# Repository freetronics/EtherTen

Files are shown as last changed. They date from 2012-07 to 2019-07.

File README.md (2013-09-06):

Freetronics EtherTen
====================
Copyright 2010-2013 Freetronics Pty Ltd  
Freetronics site:  www.freetronics.com  
Freetronics email: info@freetronics.com  

The EtherTen is a 100% Arduino Compatible Board, based on the Arduino
Uno reference design, but with improvements and updates for ease of use, cost
and getting started. It also includes on-board Ethernet with PoE (Power
-over-Ethernet) support.

Features:

 * LEDs visible on the edge
 * Micro-USB Connector
 * I2C MAC address ROM
 * Overlay guide where you need it (both top and bottom)
 * D13 pin works for everything
 * RX pin biased
 * Mounting holes, power and X3 pads
 * All connections in the same place

You can view more at our product page at:

  http://www.freetronics.com/etherten

This repository includes a handy copy of the schematic in PDF format.

INSTALLATION
------------
The design is saved as an EAGLE project. EAGLE PCB design software is
available from www.cadsoftusa.com free for non-commercial use. To use
this project download it and place the directory containing these files
into the "eagle" directory on your computer. Then open EAGLE and
navigate to Projects -> eagle -> EtherTen.

DISTRIBUTION
------------
The specific terms of distribution of this project are governed by the
license referenced below.

LICENSE
-------
This work is licensed under the
Creative Commons Attribution-Share Alike License.  
To view a copy of this license, visit

  http://creativecommons.org/licenses/by-sa/3.0/  
  http://creativecommons.org/licenses/by-sa/3.0/legalcode

or send a letter to

  Creative Commons  
  171 Second Street, Suite 300  
  San Francisco  
  California, 94105  
  USA

The "license" folder within this repository also contains copies of the
licences referenced above.

CREDITS
-------
The EtherTen was designed by Marc Alexander (marc@freetronics.com) and
Jonathan Oxer (jon@freetronics.com) based on previous work by the Arduino
team (www.arduino.cc/playground/Main/People) which includes:

 * Massimo Banzi
 * David Cuartielles
 * Tom Igoe
 * Gianluca Martino
 * David A. Mellis

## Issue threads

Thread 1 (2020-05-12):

uSD_nCS inhibits use of D4 as INPUT_PULLUP

berossm, 2020-05-12:
The uSD_nCS line passes to ground through RN6 & RN8.  As a result this overcomes the internal pull-up for D4.

For my application I needed all of inputs as pull-up.  To work around this I removed RN8 as I did not need uSD access.

My recommendation to improve this is to add another pair of pads with a trace between them like the I2C isolate that allows isolation of the D4 line between RN6D and the microcontoller.

jonoxer, 2020-05-12:
Thanks for the suggestion. D4 is joined to RN8 using the track shown in the screenshot, passing along the bottom layer. There's a small space in the region shown by the red highlight, so the track could be cut at that location.

The EtherTen is due for a big update anyway, to replace the old W5100 which is now becoming hard to get. I also want to change the USB socket to USB-C, and make a few other changes. I'll leave this bug open as a reminder for me to add a cut-track solder jumper in D4 for the next revision.

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

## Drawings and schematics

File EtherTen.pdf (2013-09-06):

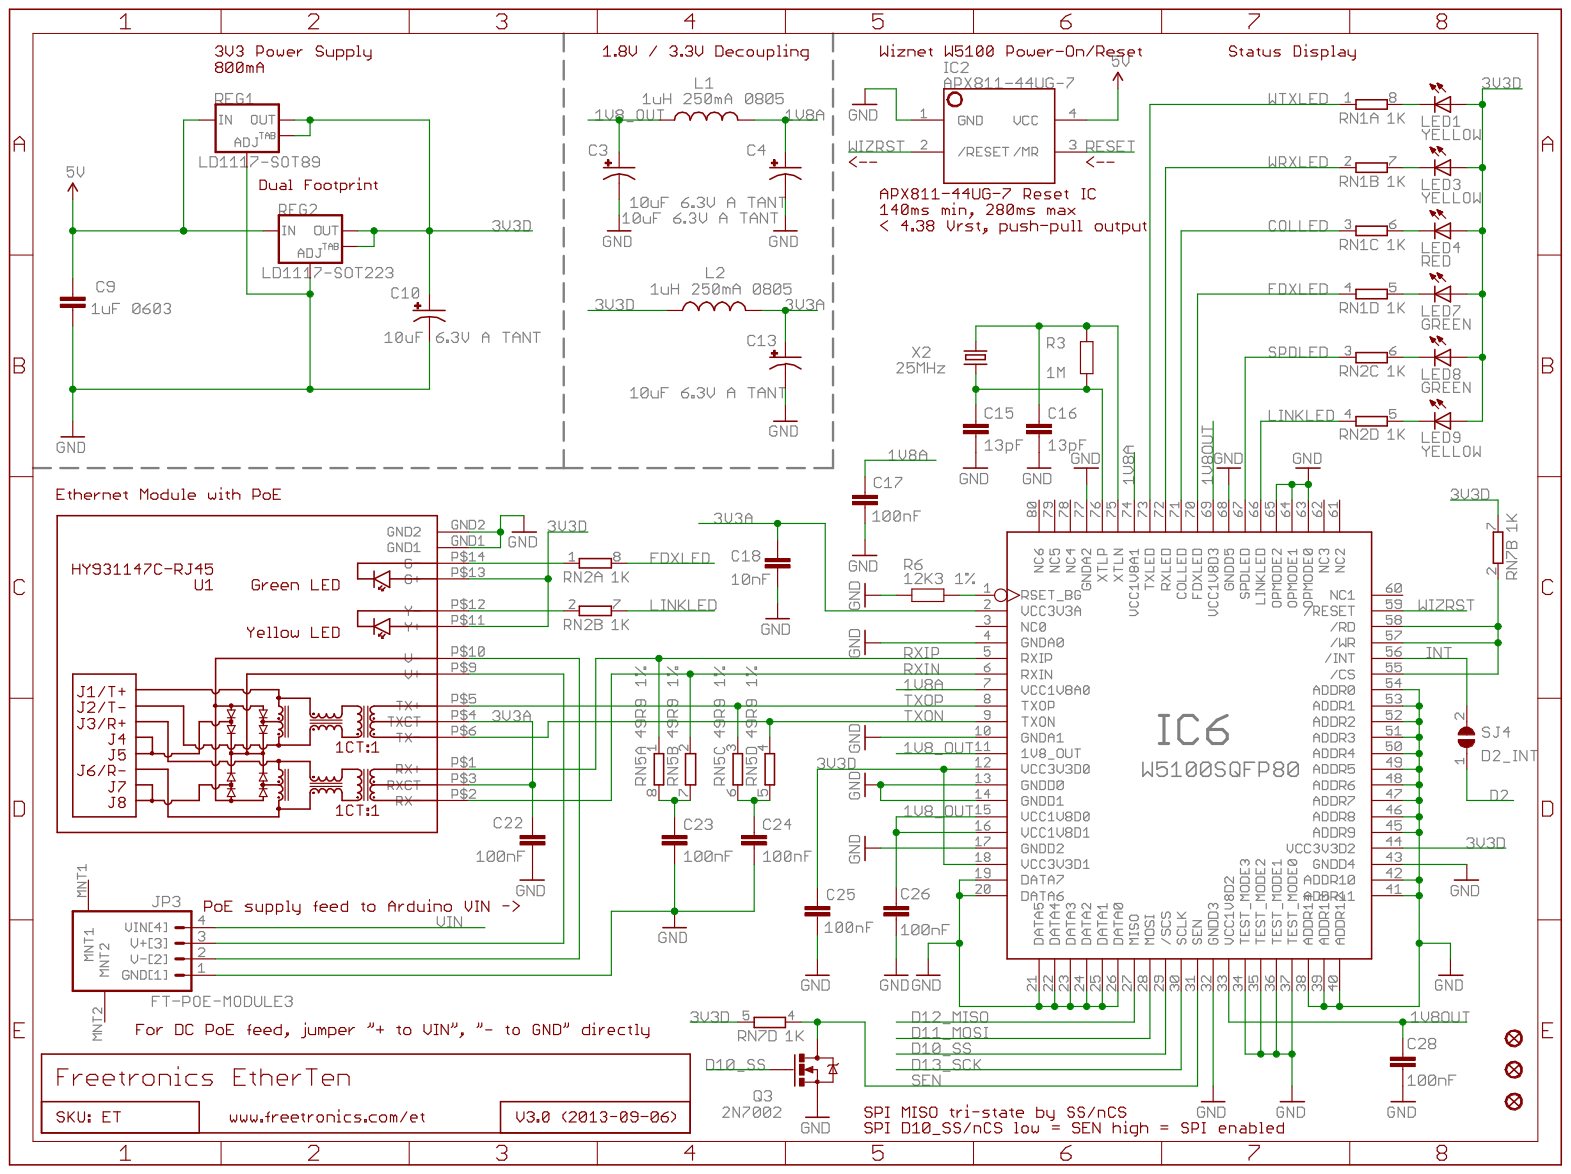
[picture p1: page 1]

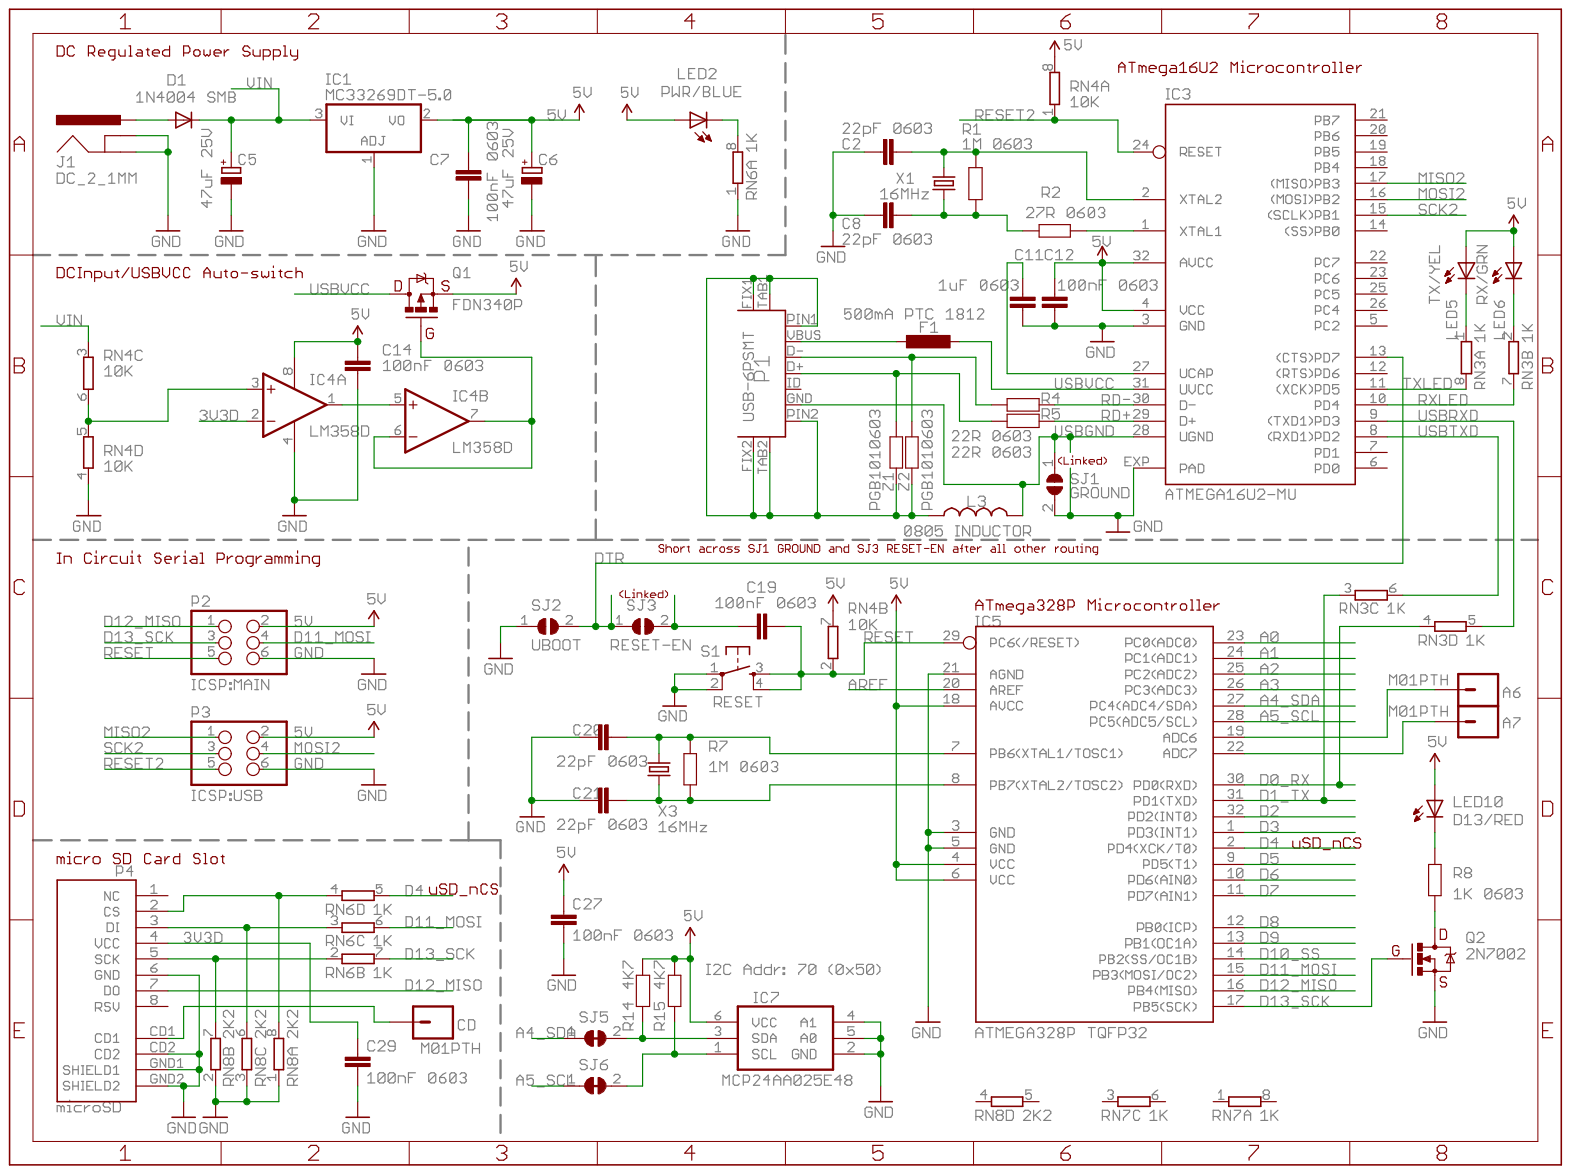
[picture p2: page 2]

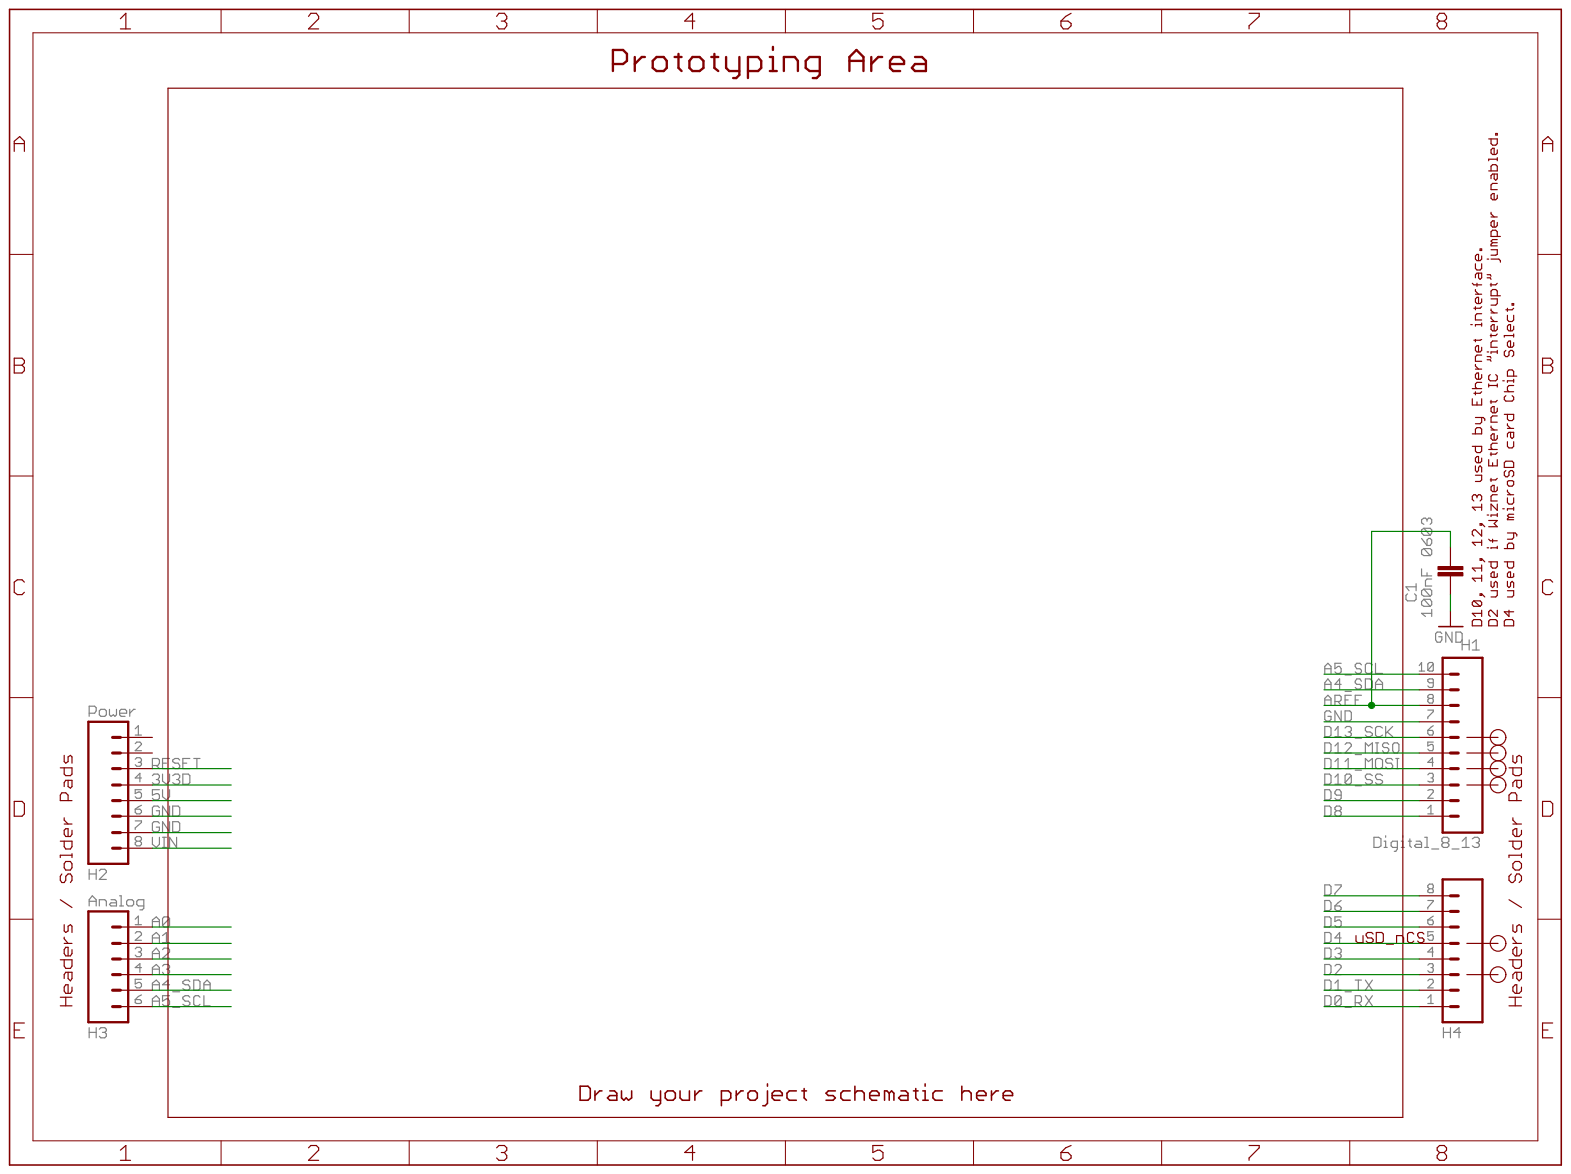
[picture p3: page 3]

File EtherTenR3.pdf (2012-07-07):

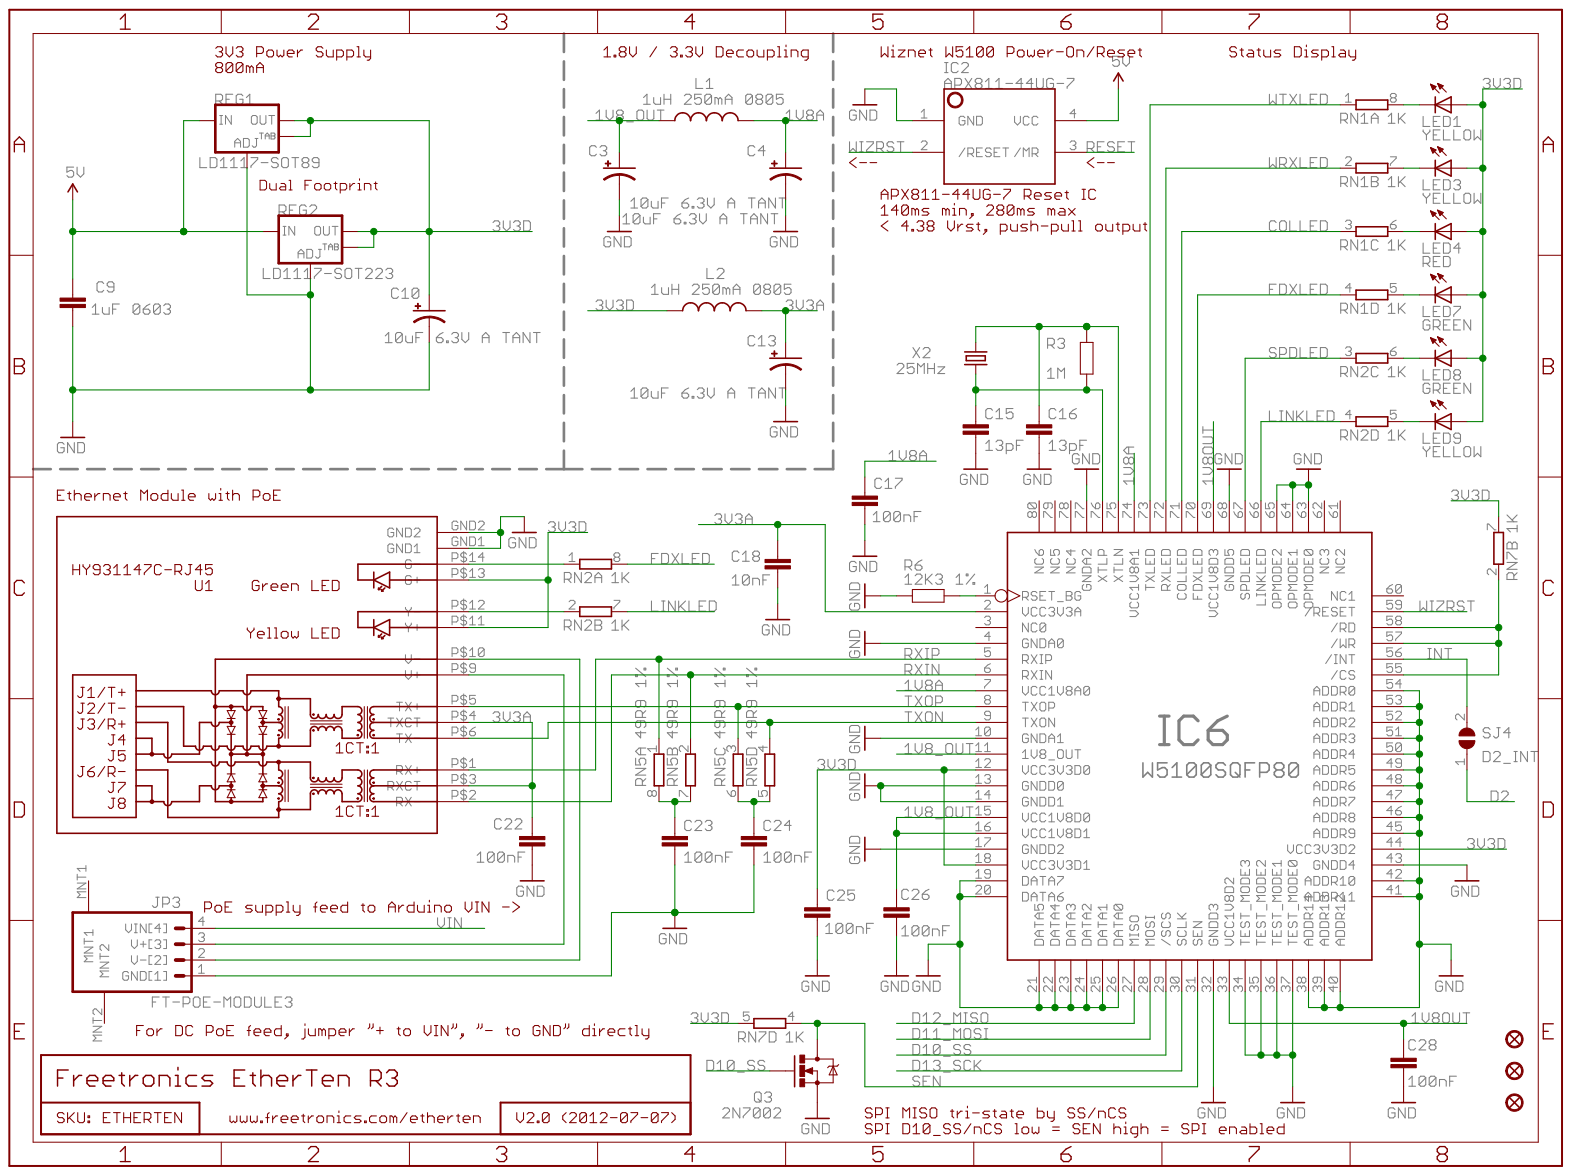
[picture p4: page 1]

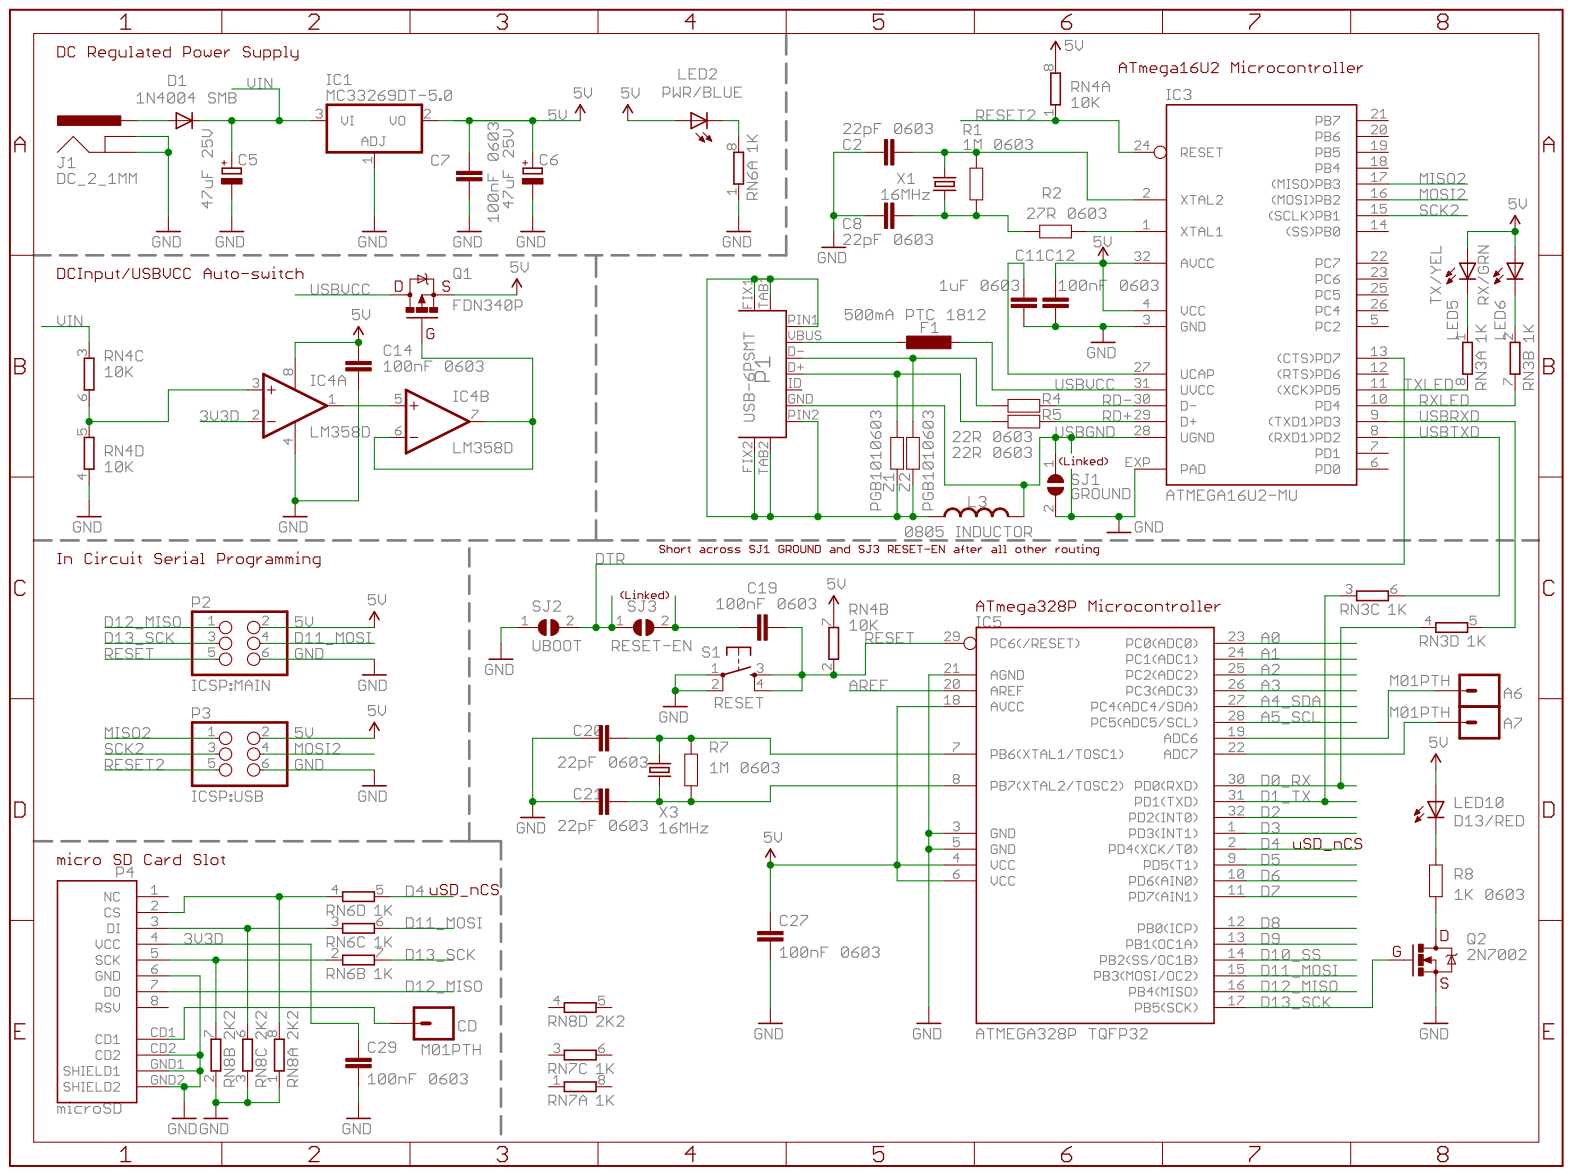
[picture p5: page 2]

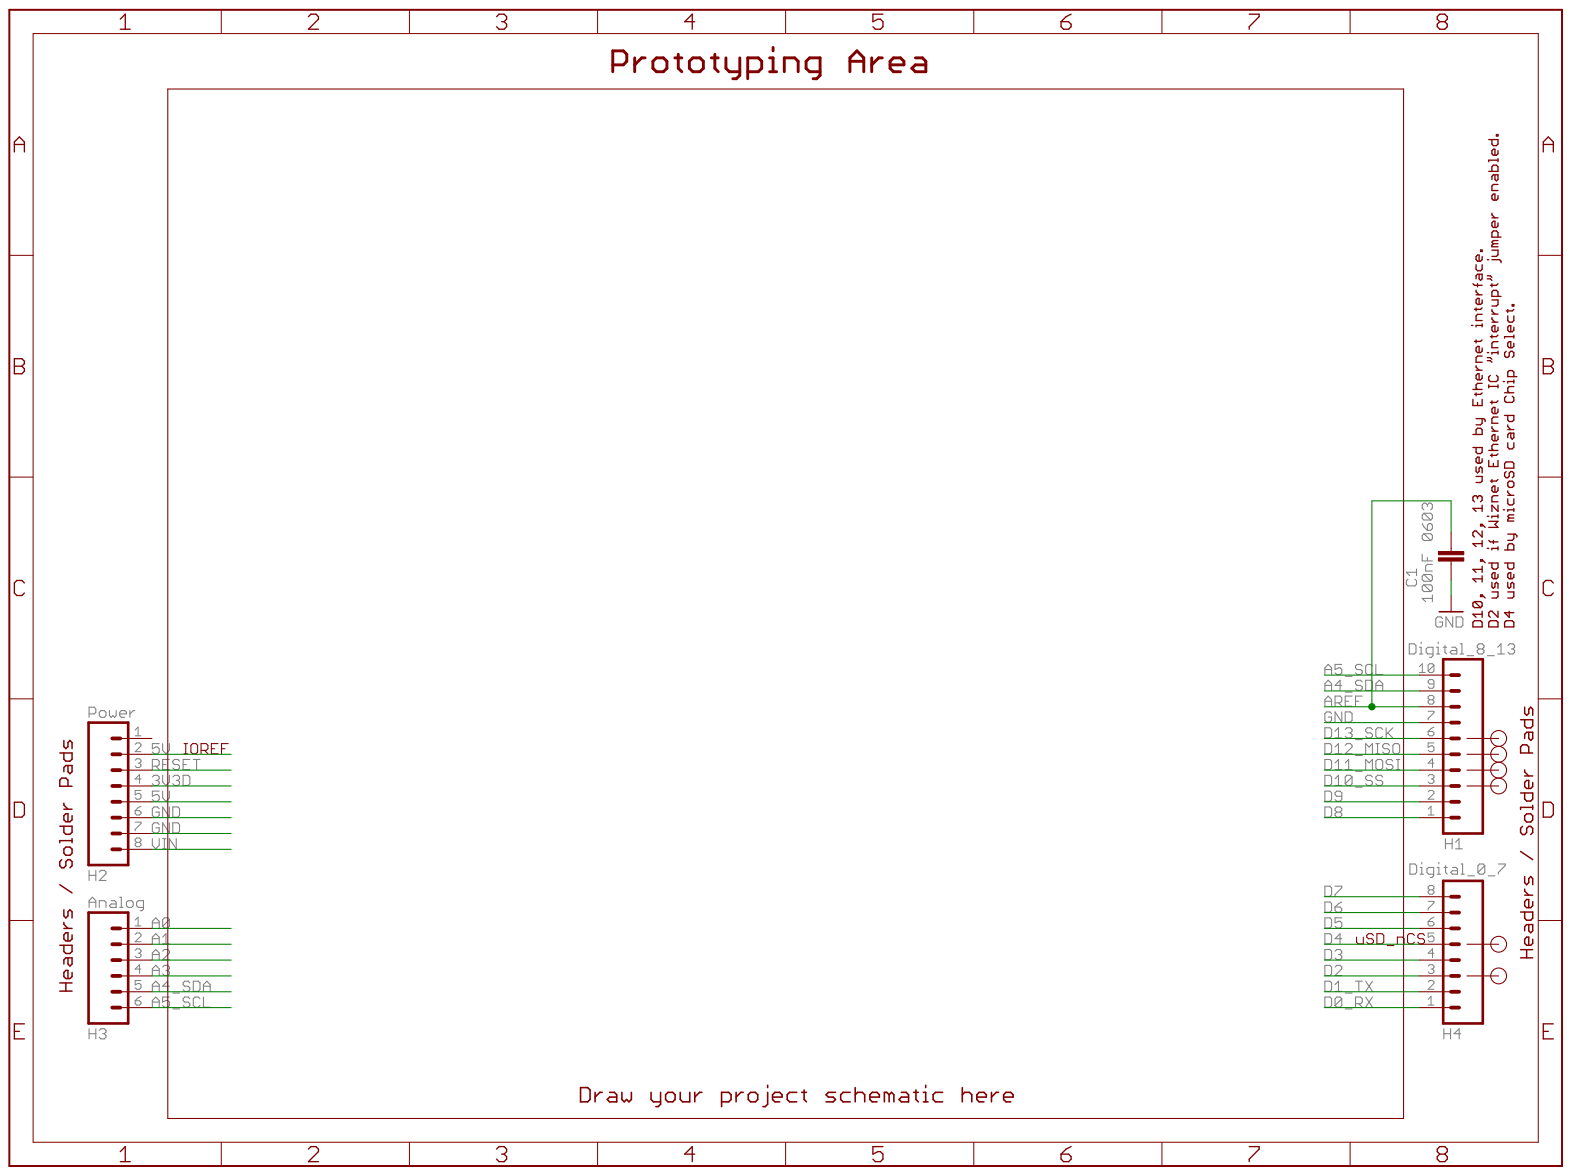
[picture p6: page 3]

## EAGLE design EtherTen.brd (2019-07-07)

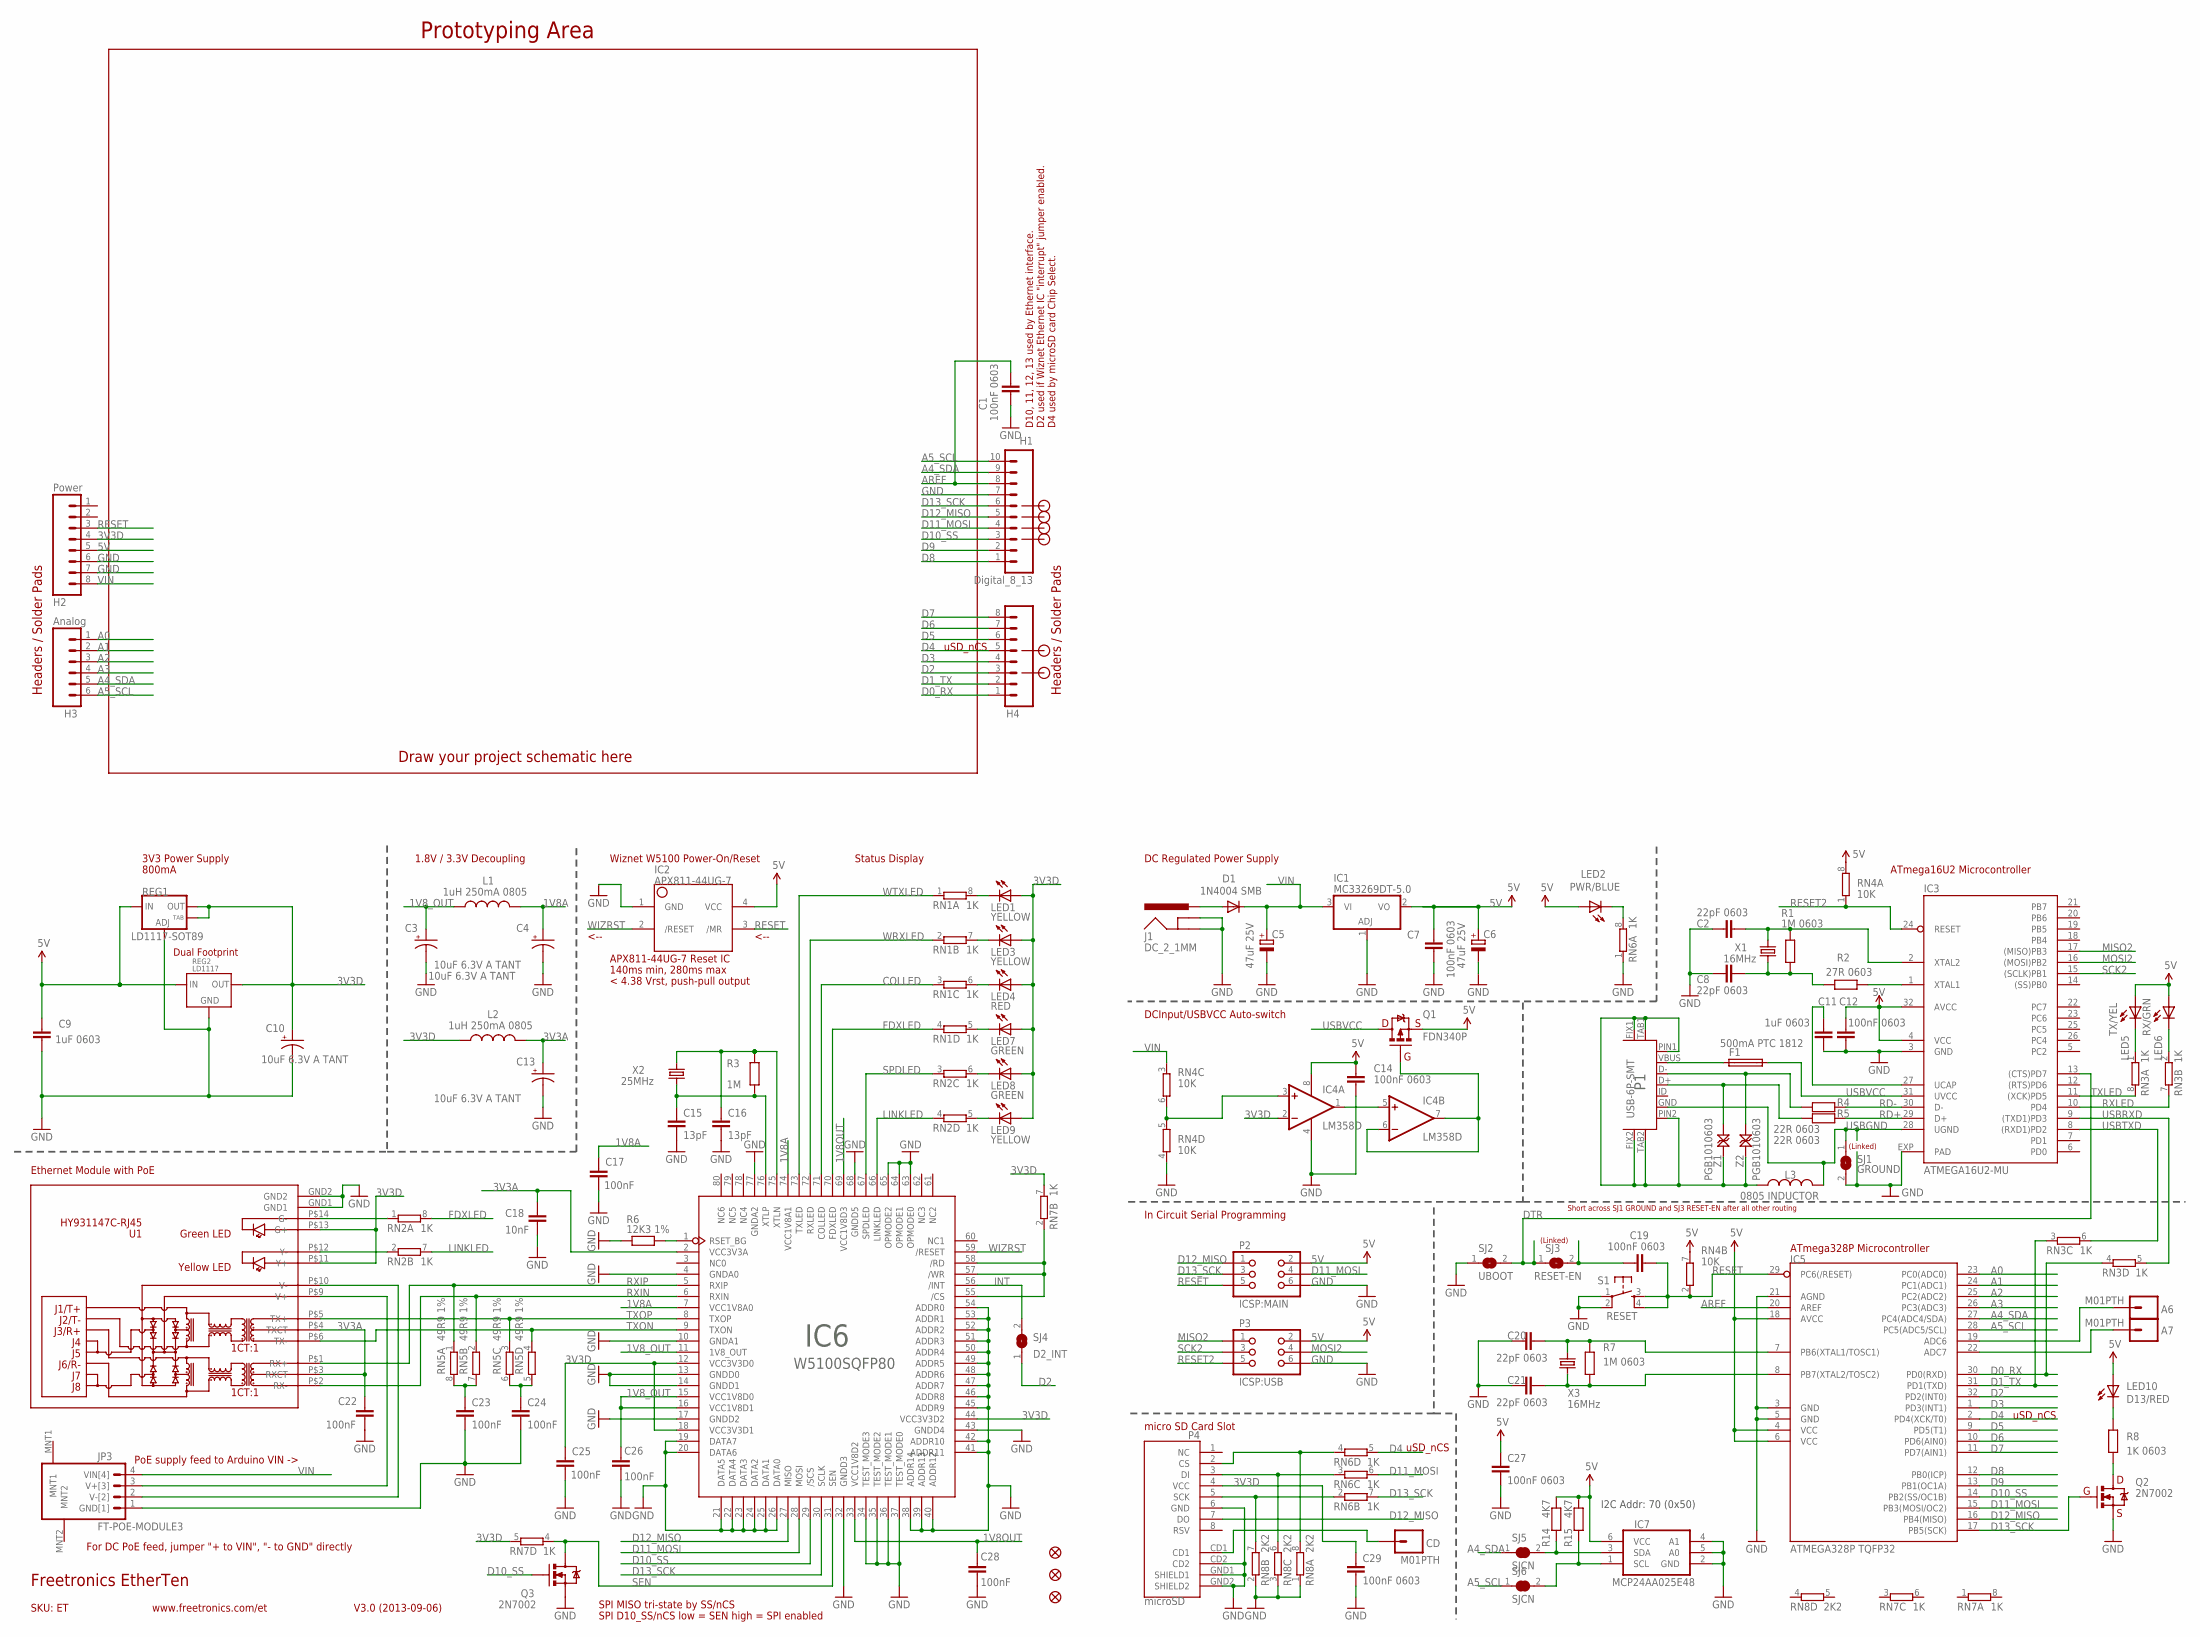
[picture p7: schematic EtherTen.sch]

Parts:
A6, A7: M01PTH; 1X01
C1, C7, C12, C14, C19, C27, C29: 100nF 0603; C0603
C2, C8, C20, C21: 22pF 0603; C0603
C3, C4, C10, C13: 10uF 6.3V A TANT; EIA3216
C5, C6: 47uF 25V; PANASONIC_D
C9, C11: 1uF 0603; C0603
C15, C16: 13pF; C0603
C17, C22, C23, C24, C25, C26, C28: 100nF; C0603
C18: 10nF; C0603
CD: M01PTH; 1X01
D1: 1N4004 SMB; SMA-DIODE
F1: 500mA PTC 1812; 1812
FID1, FID2, FID3: FIDUCIAL1X2.5; FIDUCIAL-1X2.5
H1: Digital_8_13; 1X10-S
H2: Power; 1X08-S
H3: Analog; 1X06-S
H4: Digital_0_7; 1X08-S
IC1: MC33269DT-5.0; DPACK
IC2: APX811-44UG-7; SOT143-R
IC3: ATMEGA16U2-MU; ATMEL_QFN32
IC4: LM358D; SO08
IC5: ATMEGA328P TQFP32; TQFP32-08
IC6: W5100SQFP80; SQFP80
IC7: MCP24AA025E48; SOT23-6
J1: DC_2_1MM; POWER_JACK_SLOTS
JP3: FT-POE-MODULE3; FT-POE-MODULE-NOLABEL
L1, L2: 1uH 250mA 0805; L2012C
L3: 0805 INDUCTOR; 0805-LARGE
LED1, LED3, LED9: YELLOW; LED-0603
LED2: PWR/BLUE; LED-0603
LED4: RED; LED-0603
LED5: TX/YEL; LED-0603
LED6: RX/GRN; LED-0603
LED7, LED8: GREEN; LED-0603
LED10: D13/RED; LED-0603
P1: USB-6P-SMT; USB-MICROB-MB05PMXX
P2: ICSP:MAIN; 2X03PTH
P3: ICSP:USB; 2X03PTH
P4: microSD; MICRO-SD-SOCKET-PP
Q1: FDN340P; SOT23
Q2, Q3: 2N7002; SOT23-3
R1, R7: 1M 0603; R0603
R2: 27R 0603; R0603
R3: 1M; R0603
R4, R5: 22R 0603; R0603
R6: 12K3 1%; R0603
R8: 1K 0603; R0603
R14, R15: 4K7; R0603
REG1: LD1117-SOT89; SOT89
REG2: LD1117; SOT-223
RN1, RN2, RN3, RN6, RN7: 1K; CAY16
RN4: 10K; CAY16
RN5: 49R9 1%; CAY16
RN8: 2K2; CAY16
S1: RESET; TACTILE_SMD-6MM
SJ1: GROUND; SJ
SJ2: UBOOT; SJ
SJ3: RESET-EN; SJ
SJ4: D2_INT; SJ
SJ5, SJ6: SJCN; SJC
U1: HY931147C-RJ45; HY931147C
X1, X3: 16MHz; HC49U-V
X2: 25MHz; HC49U-V
Z1, Z2: PGB1010603; TVS0603

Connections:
1V8A: C4.A (+), C17.1, IC6.7 (VCC1V8A0), IC6.74 (VCC1V8A1), L1.2
1V8OUT: C28.1, IC6.33 (VCC1V8D2), IC6.69 (VCC1V8D3)
1V8_OUT: C3.A (+), C26.1, IC6.11 (1V8_OUT), IC6.15 (VCC1V8D0), IC6.16 (VCC1V8D1), L1.1
3V3A: C13.A (+), C18.1, C22.1, IC6.2 (VCC3V3A), L2.2, U1.P$3 (RXCT), U1.P$4 (TXCT)
3V3D: C10.A (+), C25.1, C29.1, H2.4, IC4.2 (-IN), IC6.12 (VCC3V3D0), IC6.18 (VCC3V3D1), IC6.44 (VCC3V3D2), L2.1, LED1.A, LED3.A, LED4.A, LED7.A, LED8.A, LED9.A, P4.4 (VCC), REG1.2 (OUT), REG1.4 (OUT), REG2.2 (OUT), REG2.4 (OUT), RN7.5 (2), RN7.7 (2), U1.P$11 (Y+), U1.P$13 (G+)
5V: C6.+, C7.1, C9.1, C12.1, C14.1, C27.1, H2.5, IC1.2 (VO), IC2.4 (VCC), IC3.4 (VCC), IC3.32 (AVCC), IC4.8 (V+), IC5.4 (VCC), IC5.6 (VCC), IC5.18 (AVCC), IC7.6 (VCC), LED2.A, LED5.A, LED6.A, LED10.A, P2.2, P3.2, Q1.2 (S), R14.1, R15.1, REG1.3 (IN), REG2.3 (IN), RN4.7 (2), RN4.8 (2)
A0: H3.1, IC5.23 (PC0(ADC0))
A1: H3.2, IC5.24 (PC1(ADC1))
A2: H3.3, IC5.25 (PC2(ADC2))
A3: H3.4, IC5.26 (PC3(ADC3))
A4_SDA: H1.9, H3.5, IC5.27 (PC4(ADC4/SDA)), SJ5.1
A5_SCL: H1.10, H3.6, IC5.28 (PC5(ADC5/SCL)), SJ6.1
AREF: C1.1, H1.8, IC5.20 (AREF)
COLLED: IC6.71 (COLLED), RN1.3 (1)
D0_RX: H4.1, IC5.30 (PD0(RXD)), RN3.4 (1)
D1_TX: H4.2, IC5.31 (PD1(TXD)), RN3.3 (1)
D2: H4.3, IC5.32 (PD2(INT0)), SJ4.1
D3: H4.4, IC5.1 (PD3(INT1))
D4: H4.5, IC5.2 (PD4(XCK/T0)), RN6.5 (2)
D5: H4.6, IC5.9 (PD5(T1))
D6: H4.7, IC5.10 (PD6(AIN0))
D7: H4.8, IC5.11 (PD7(AIN1))
D8: H1.1, IC5.12 (PB0(ICP))
D9: H1.2, IC5.13 (PB1(OC1A))
D10_SS: H1.3, IC5.14 (PB2(SS/OC1B)), IC6.29 (/SCS), Q3.1 (G)
D11_MOSI: H1.4, IC5.15 (PB3(MOSI/OC2)), IC6.28 (MOSI), P2.4, RN6.6 (2)
D12_MISO: H1.5, IC5.16 (PB4(MISO)), IC6.27 (MISO), P2.1, P4.7 (DO)
D13_SCK: H1.6, IC5.17 (PB5(SCK)), IC6.30 (SCLK), P2.3, Q2.1 (G), RN6.7 (2)
DTR: IC3.13 ((CTS)PD7), SJ2.2, SJ3.1
FDXLED: IC6.70 (FDXLED), RN1.4 (1), RN2.8 (2)
GND: C1.2, C2.1, C3.C (-), C4.C (-), C5.-, C6.-, C7.2, C8.1, C9.2, C10.C (-), C11.2, C12.2, C13.C (-), C14.2, C15.2, C16.2, C17.2, C18.2, C20.1, C21.1, C22.2, C23.2, C24.2, C25.2, C26.2, C27.2, C28.2, C29.2, H1.7, H2.6, H2.7, IC1.1 (ADJ), IC2.1 (GND), IC3.3 (GND), IC3.EXP (PAD), IC4.4 (V-), IC5.3 (GND), IC5.5 (GND), IC5.21 (AGND), IC6.4 (GNDA0), IC6.10 (GNDA1), IC6.13 (GNDD0), IC6.14 (GNDD1), IC6.17 (GNDD2), IC6.19 (DATA7), IC6.20 (DATA6), IC6.21 (DATA5), IC6.22 (DATA4), IC6.23 (DATA3), IC6.24 (DATA2), IC6.25 (DATA1), IC6.26 (DATA0), IC6.32 (GNDD3), IC6.34 (TEST_MODE3), IC6.35 (TEST_MODE2), IC6.36 (TEST_MODE1), IC6.37 (TEST_MODE0), IC6.38 (ADDR14), IC6.39 (ADDR13), IC6.40 (ADDR12), IC6.41 (ADDR11), IC6.42 (ADDR10), IC6.43 (GNDD4), IC6.45 (ADDR9), IC6.46 (ADDR8), IC6.47 (ADDR7), IC6.48 (ADDR6), IC6.49 (ADDR5), IC6.50 (ADDR4), IC6.51 (ADDR3), IC6.52 (ADDR2), IC6.53 (ADDR1), IC6.54 (ADDR0), IC6.63 (OPMODE0), IC6.64 (OPMODE1), IC6.65 (OPMODE2), IC6.68 (GNDD5), IC6.77 (GNDA2), IC7.2 (GND), IC7.4 (A1), IC7.5 (A0), J1.GND, J1.GNDBREAK, JP3.1 (GND[1]), P2.6, P3.6, P4.6 (GND), P4.CD2, P4.GND1 (SHIELD1), P4.GND2 (SHIELD2), Q2.2 (S), Q3.2 (S), R6.1, REG1.1 (ADJ), REG2.1 (GND), RN4.4 (1), RN6.1, RN8.1, RN8.2 (1), RN8.3 (1), S1.1, S1.2, SJ1.2, SJ2.1, U1.GND1, U1.GND2
INT: IC6.56 (/INT), SJ4.2
LINKLED: IC6.66 (LINKLED), RN2.4 (1), RN2.7 (2)
MISO2: IC3.17 ((MISO)PB3), P3.1
MOSI2: IC3.16 ((MOSI)PB2), P3.4
unnamed: C24.1, RN5.5 (2), RN5.6 (2)
unnamed: C20.2, IC5.7 (PB6(XTAL1/TOSC1)), R7.2, X3.2
unnamed: C19.1, SJ3.2
unnamed: LED10.C, R8.2
unnamed: IC7.1 (SCL), R15.2, SJ6.2
unnamed: Q2.3 (D), R8.1
unnamed: C21.2, IC5.8 (PB7(XTAL2/TOSC2)), R7.1, X3.1
unnamed: IC3.1 (XTAL1), R2.1
unnamed: L3.1, P1.FIX1, P1.FIX2, P1.PIN1, P1.PIN2, P1.TAB1, P1.TAB2, Z1.2, Z2.2
unnamed: LED6.C, RN3.2 (1)
unnamed: IC4.3 (+IN), RN4.5 (2), RN4.6 (2)
unnamed: LED5.C, RN3.1
unnamed: LED2.C, RN6.8 (2)
unnamed: P1.D+, R5.2, Z1.1
unnamed: P1.D-, R4.2, Z2.1
unnamed: IC4.6 (-IN), IC4.7 (OUT), Q1.1 (G)
unnamed: IC4.1 (OUT), IC4.5 (+IN)
unnamed: P4.2 (CS), RN6.4 (1), RN8.8 (2)
unnamed: A7.1, IC5.22 (ADC7)
unnamed: A6.1, IC5.19 (ADC6)
unnamed: CD.1, P4.CD1
unnamed: P4.5 (SCK), RN6.2 (1), RN8.7 (2)
unnamed: P4.3 (DI), RN6.3 (1), RN8.6 (2)
unnamed: LED8.C, RN2.6 (2)
unnamed: IC6.55 (/CS), IC6.57 (/WR), IC6.58 (/RD), RN7.2 (1)
unnamed: LED9.C, RN2.5 (2)
unnamed: IC7.3 (SDA), R14.2, SJ5.2
unnamed: D1.A, J1.PWR
unnamed: RN2.1, U1.P$14 (G-)
unnamed: JP3.3 (V+[3]), U1.P$9 (V+)
unnamed: JP3.2 (V-[2]), U1.P$10 (V-)
unnamed: C2.2, IC3.2 (XTAL2), R1.2, X1.2
unnamed: C8.2, R1.1, R2.2, X1.1
unnamed: F1.1, P1.VBUS
unnamed: C11.1, IC3.27 (UCAP)
unnamed: C23.1, RN5.7 (2), RN5.8 (2)
unnamed: IC6.1 (RSET_BG), R6.2
unnamed: LED7.C, RN1.5 (2)
unnamed: LED4.C, RN1.6 (2)
unnamed: LED3.C, RN1.7 (2)
unnamed: LED1.C, RN1.8 (2)
unnamed: RN2.2 (1), U1.P$12 (Y-)
RD+: IC3.29 (D+), R5.1
RD-: IC3.30 (D-), R4.1
RESET: C19.2, H2.3, IC2.3 (/MR), IC5.29 (PC6(/RESET)), P2.5, RN4.2 (1), S1.3, S1.4
RESET2: IC3.24 (RESET), P3.5, RN4.1
RXIN: IC6.6 (RXIN), RN5.2 (1), U1.P$2 (RX-)
RXIP: IC6.5 (RXIP), RN5.1, U1.P$1 (RX+)
RXLED: IC3.10 (PD4), RN3.7 (2)
SCK2: IC3.15 ((SCLK)PB1), P3.3
SEN: IC6.31 (SEN), Q3.3 (D), RN7.4 (1)
SPDLED: IC6.67 (SPDLED), RN2.3 (1)
TXLED: IC3.11 ((XCK)PD5), RN3.8 (2)
TXON: IC6.9 (TXON), RN5.4 (1), U1.P$6 (TX-)
TXOP: IC6.8 (TXOP), RN5.3 (1), U1.P$5 (TX+)
USBGND: IC3.28 (UGND), L3.2, P1.GND, SJ1.1
USBRXD: IC3.9 ((TXD1)PD3), RN3.5 (2)
USBTXD: IC3.8 ((RXD1)PD2), RN3.6 (2)
USBVCC: F1.2, IC3.31 (UVCC), Q1.3 (D)
VIN: C5.+, D1.C, H2.8, IC1.3 (VI), JP3.4 (VIN[4]), RN4.3 (1)
WIZRST: IC2.2 (/RESET), IC6.59 (/RESET)
WRXLED: IC6.72 (RXLED), RN1.2 (1)
WTXLED: IC6.73 (TXLED), RN1.1
XTLN: C16.1, IC6.75 (XTLN), R3.2, X2.2
XTLP: C15.1, IC6.76 (XTLP), R3.1, X2.1

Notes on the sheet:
Prototyping Area
SKU: ET
3V3 Power Supply
Status Display
Headers / Solder Pads
Dual Footprint
1.8V / 3.3V Decoupling
Draw your project schematic here
D10, 11, 12, 13 used by Ethernet interface.
D2 used if Wiznet Ethernet IC "interrupt" jumper enabled.
PoE supply feed to Arduino VIN ->
SPI MISO tri-state by SS/nCS
SPI D10_SS/nCS low = SEN high = SPI enabled
For DC PoE feed, jumper "+ to VIN", "- to GND" directly
DC Regulated Power Supply
ATmega328P Microcontroller
APX811-44UG-7 Reset IC
140ms min, 280ms max
ATmega16U2 Microcontroller
DCInput/USBVCC Auto-switch
Wiznet W5100 Power-On/Reset
uSD_nCS
800mA
In Circuit Serial Programming
micro SD Card Slot
Freetronics EtherTen
V3.0 (2013-09-06)
www.freetronics.com/et
Ethernet Module with PoE
< 4.38 Vrst, push-pull output
<--
D4 used by microSD card Chip Select.
(Linked)
Short across SJ1 GROUND and SJ3 RESET-EN after all other routing
I2C Addr: 70 (0x50)

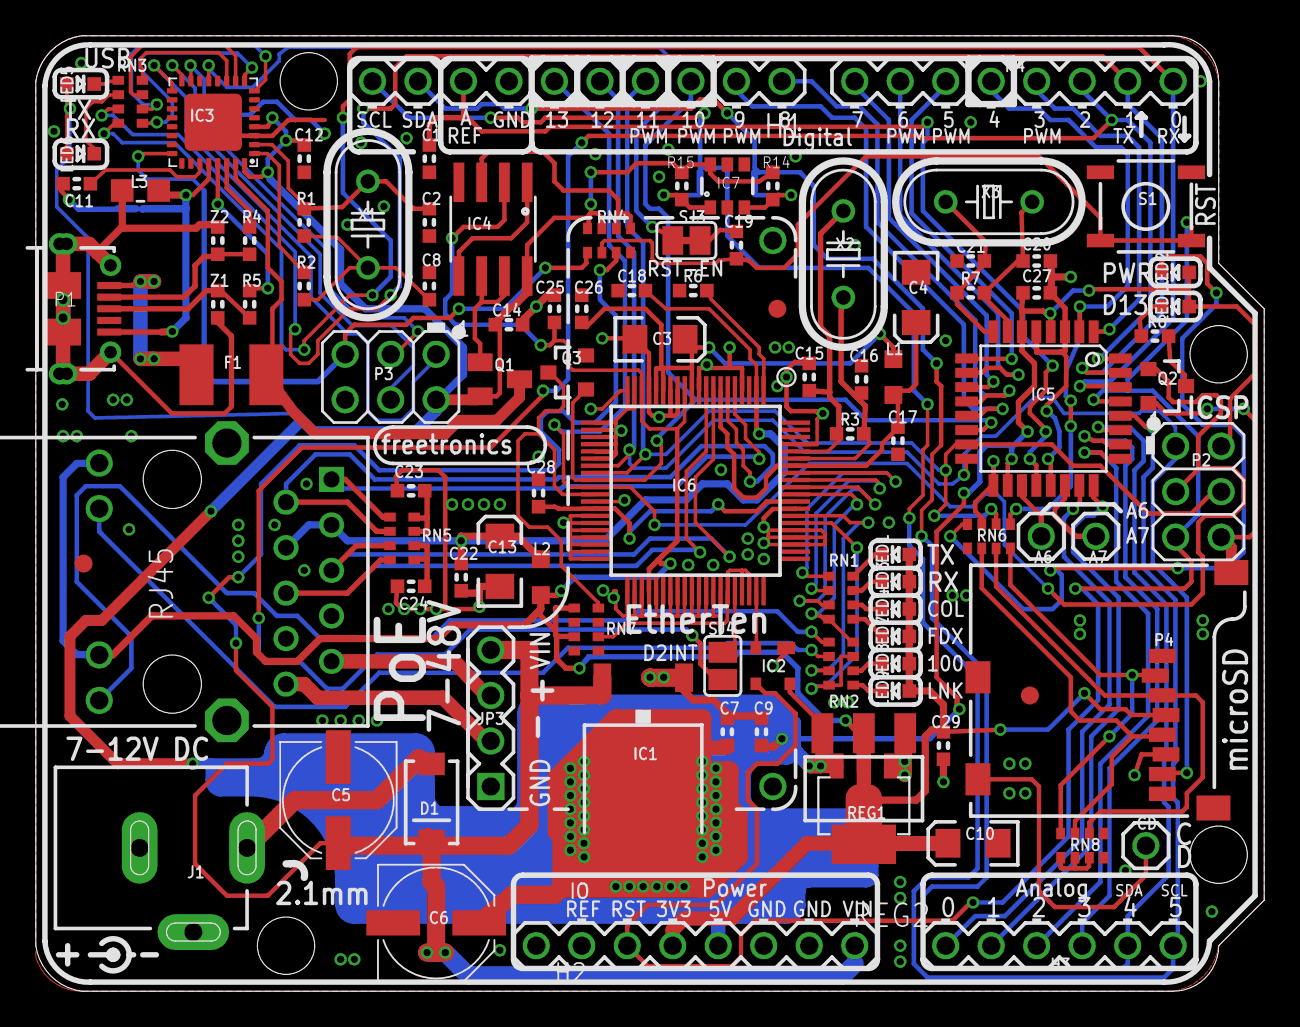
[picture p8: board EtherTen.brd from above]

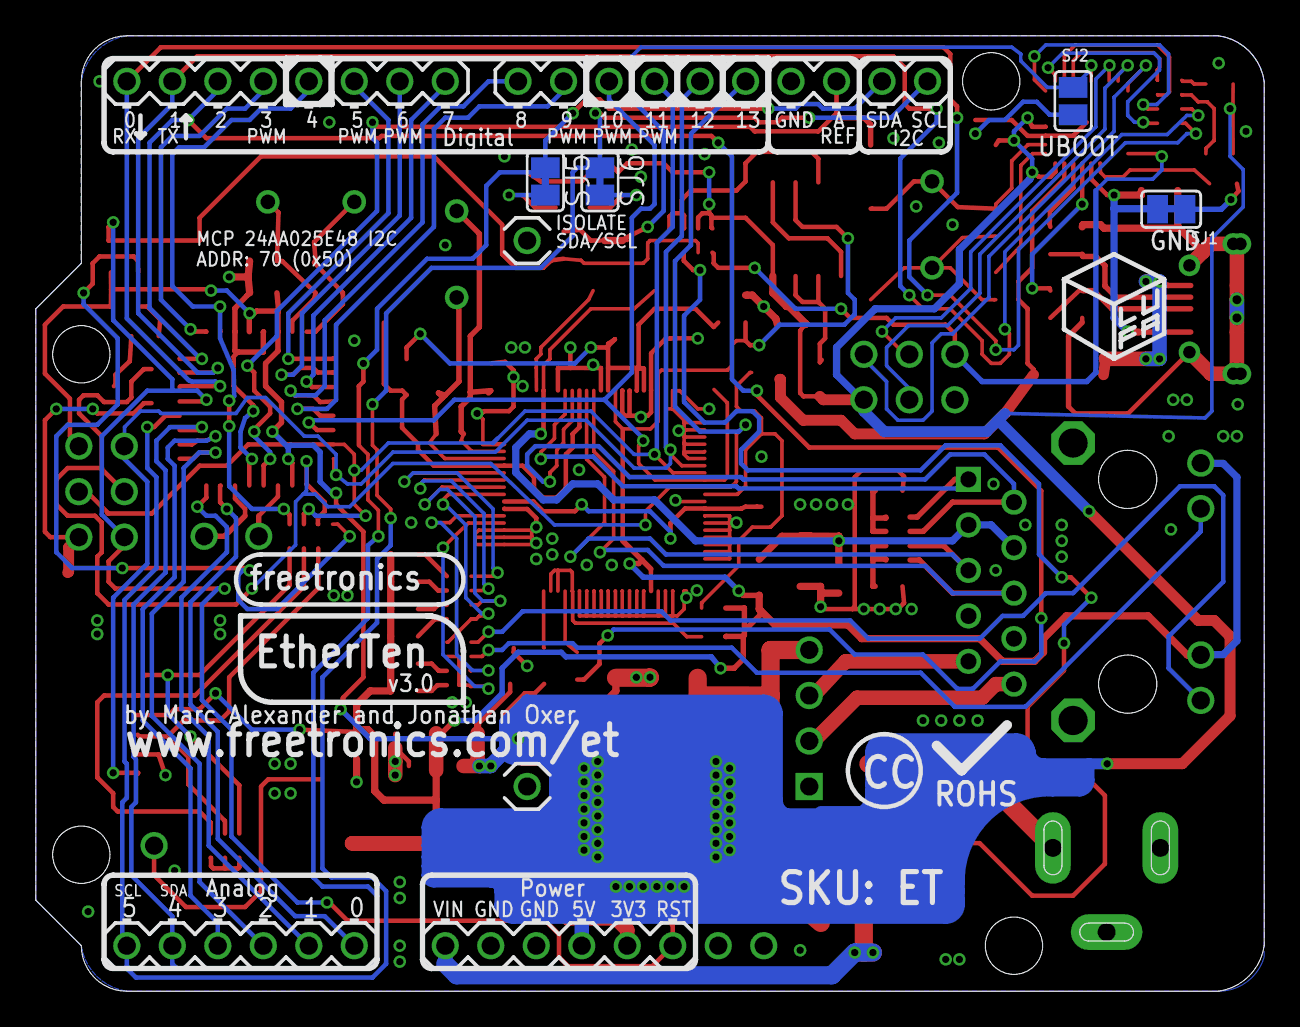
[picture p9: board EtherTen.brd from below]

Board: 2 copper layers, 68.6 x 53.3 mm, 103 parts (4 on the bottom side), 100 nets.

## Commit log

2010-06-27 Initial creation of schematic and PCB based on TwentyTen
    [EtherTen.brd, EtherTen.sch]
2010-06-27 Added Ethernet section to schematic
    [EtherTen.brd, EtherTen.sch]
2010-06-27 Replaced fiducial markers
    [EtherTen.brd, EtherTen.sch]
2010-07-08 Latest merged ES and TT
    [EtherTen.brd, EtherTen.sch]
2010-08-11 Recreated project by merging TwentyTen and Ethernet Shield
    [EtherTen.brd, EtherTen.sch]
2010-08-13 Removed parts duplicated between TT and ES schematics, and updated schematic layout
    [EtherTen.sch]
2010-08-13 Start of shoving things into place
    [EtherTen.brd]
2010-08-24 Replaced AVR package with TQFP32
    [EtherTen.sch]
2010-08-24 Moved PoE header back to left of board and added sub-board mounting holes
    [EtherTen.brd, EtherTen.sch]
2010-09-19 Moved parts closer to board
    [EtherTen.brd]
2010-09-20 Removed header breakouts and switched to TT style header labels
    [EtherTen.brd, EtherTen.sch]
2010-09-23 New locations, ripup ready for rework
    [EtherTen.brd]
2010-11-10 Squeezing and rearranging parts, new notes
    [EtherTen.brd, EtherTen.sch]
2011-02-19 New sch passes ERC
    [EtherTen.brd, EtherTen.sch]
2011-02-21 Lots of squeezing
    [EtherTen.brd, EtherTen.sch]
2011-02-23 All squeezed into pcb outline
    [EtherTen.brd, EtherTen.sch]
2011-03-10 Last fiddly routes
    [EtherTen.brd, EtherTen.sch]
2011-03-16 Squeezy tracks
    [EtherTen.brd]
2011-03-17 Zero airwires :)
    [EtherTen.brd, EtherTen.sch]
2011-03-17 Last DRC checks
    [EtherTen.brd]
2011-03-17 TL Polygon orphans on, more notes
    [EtherTen.brd]
2011-03-17 v1_0 production release
    [EtherTen.brd, EtherTen.sch]
2011-05-08 v1.1 - Pin usage on silkscreen artwork, more heatsink vias and area, microSD CD pad revision. Parts not moved.
    [EtherTen.brd, EtherTen.sch, EtherTen_v1_0_release.brd]
2011-05-08 v1.1 PDF sch renamed to suit
    [EtherTen_v1_0_release.brd]
2012-07-04 Renamed project files for R3 version
    [EtherTenR3.brd, EtherTenR3.sch]
2012-07-04 Initial changes to R3
    [EtherTenR3.brd, EtherTenR3.sch]
2012-07-05 Beginning of conversion to R3
    [EtherTenR3.brd, EtherTenR3.sch]
2012-07-06 Routing for R3 revision
    [EtherTenR3.brd, EtherTenR3.sch]
2012-07-06 More routing for R3
    [EtherTenR3.brd, EtherTenR3.sch]
2012-07-06 Improved I2C and ICSP markings; ERC and DRC for release
    [EtherTenR3.brd, EtherTenR3.sch]
2012-07-06 Improved designator visibility
    [EtherTenR3.brd]
2012-07-07 Production release R3 v2.0 files
    [EtherTenR3.brd, EtherTenR3.sch]
2013-09-06 Added I2C MAC ROM in preparation for v3.0
    [EtherTen.brd, EtherTen.sch]
2013-09-06 Added v3.0 schematic PDF
2019-07-01 Replaced most parts using SuperHouse library to add 3D models
    [EtherTen.brd, EtherTen.sch]
2019-07-07 Replaced more parts using SuperHouse libraries
    [EtherTen.brd, EtherTen.sch]

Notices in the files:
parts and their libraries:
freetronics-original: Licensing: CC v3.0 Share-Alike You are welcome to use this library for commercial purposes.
